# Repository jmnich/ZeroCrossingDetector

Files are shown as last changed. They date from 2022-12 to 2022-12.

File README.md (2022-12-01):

# Zero Crossing Detector (ZCD) 
*Designed for use with Fourier Transform Spectrometers.* 
This device converts symmetric sinusoidal signal from the reference beam detector into a TTL-compatible trigger for acquisition. 

Main features: 
- two TTL outputs 
- one intermediate monitor output
- one input 
- requires an external +-5 V symmetric supply
- accepts signals up to 20 V AC peak-peak +- 10 V DC
- input frequency up to 5 MHz
- hysteresis selectable with a rotary switch from about 20mV up to 2V 

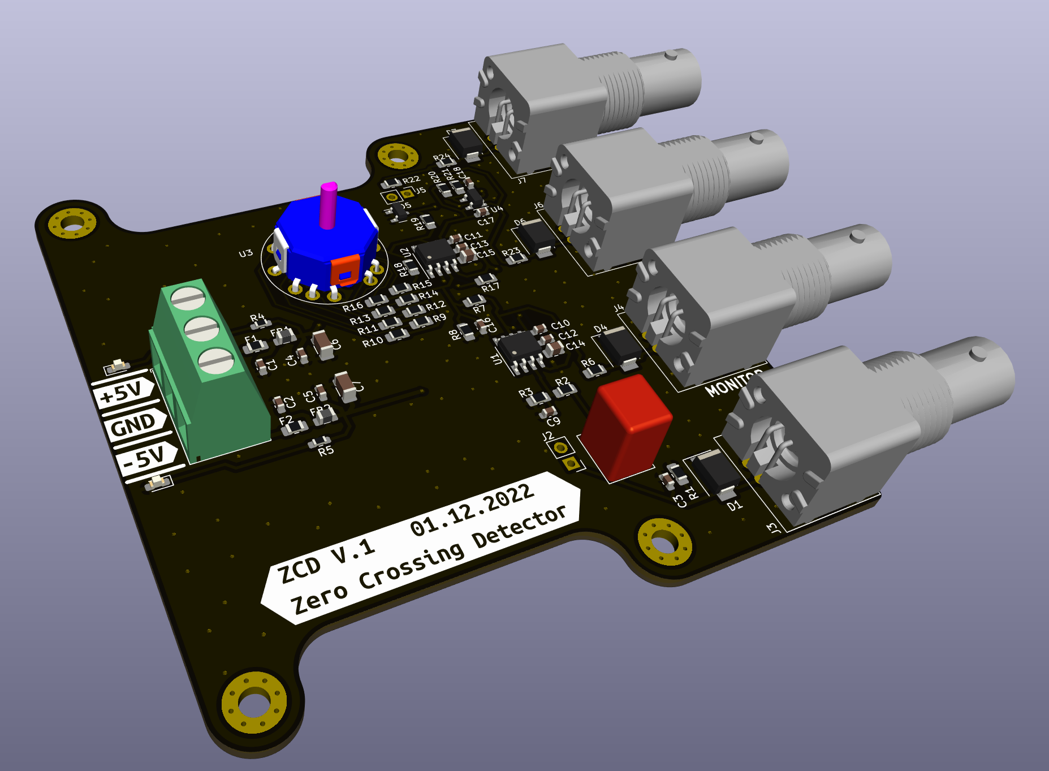
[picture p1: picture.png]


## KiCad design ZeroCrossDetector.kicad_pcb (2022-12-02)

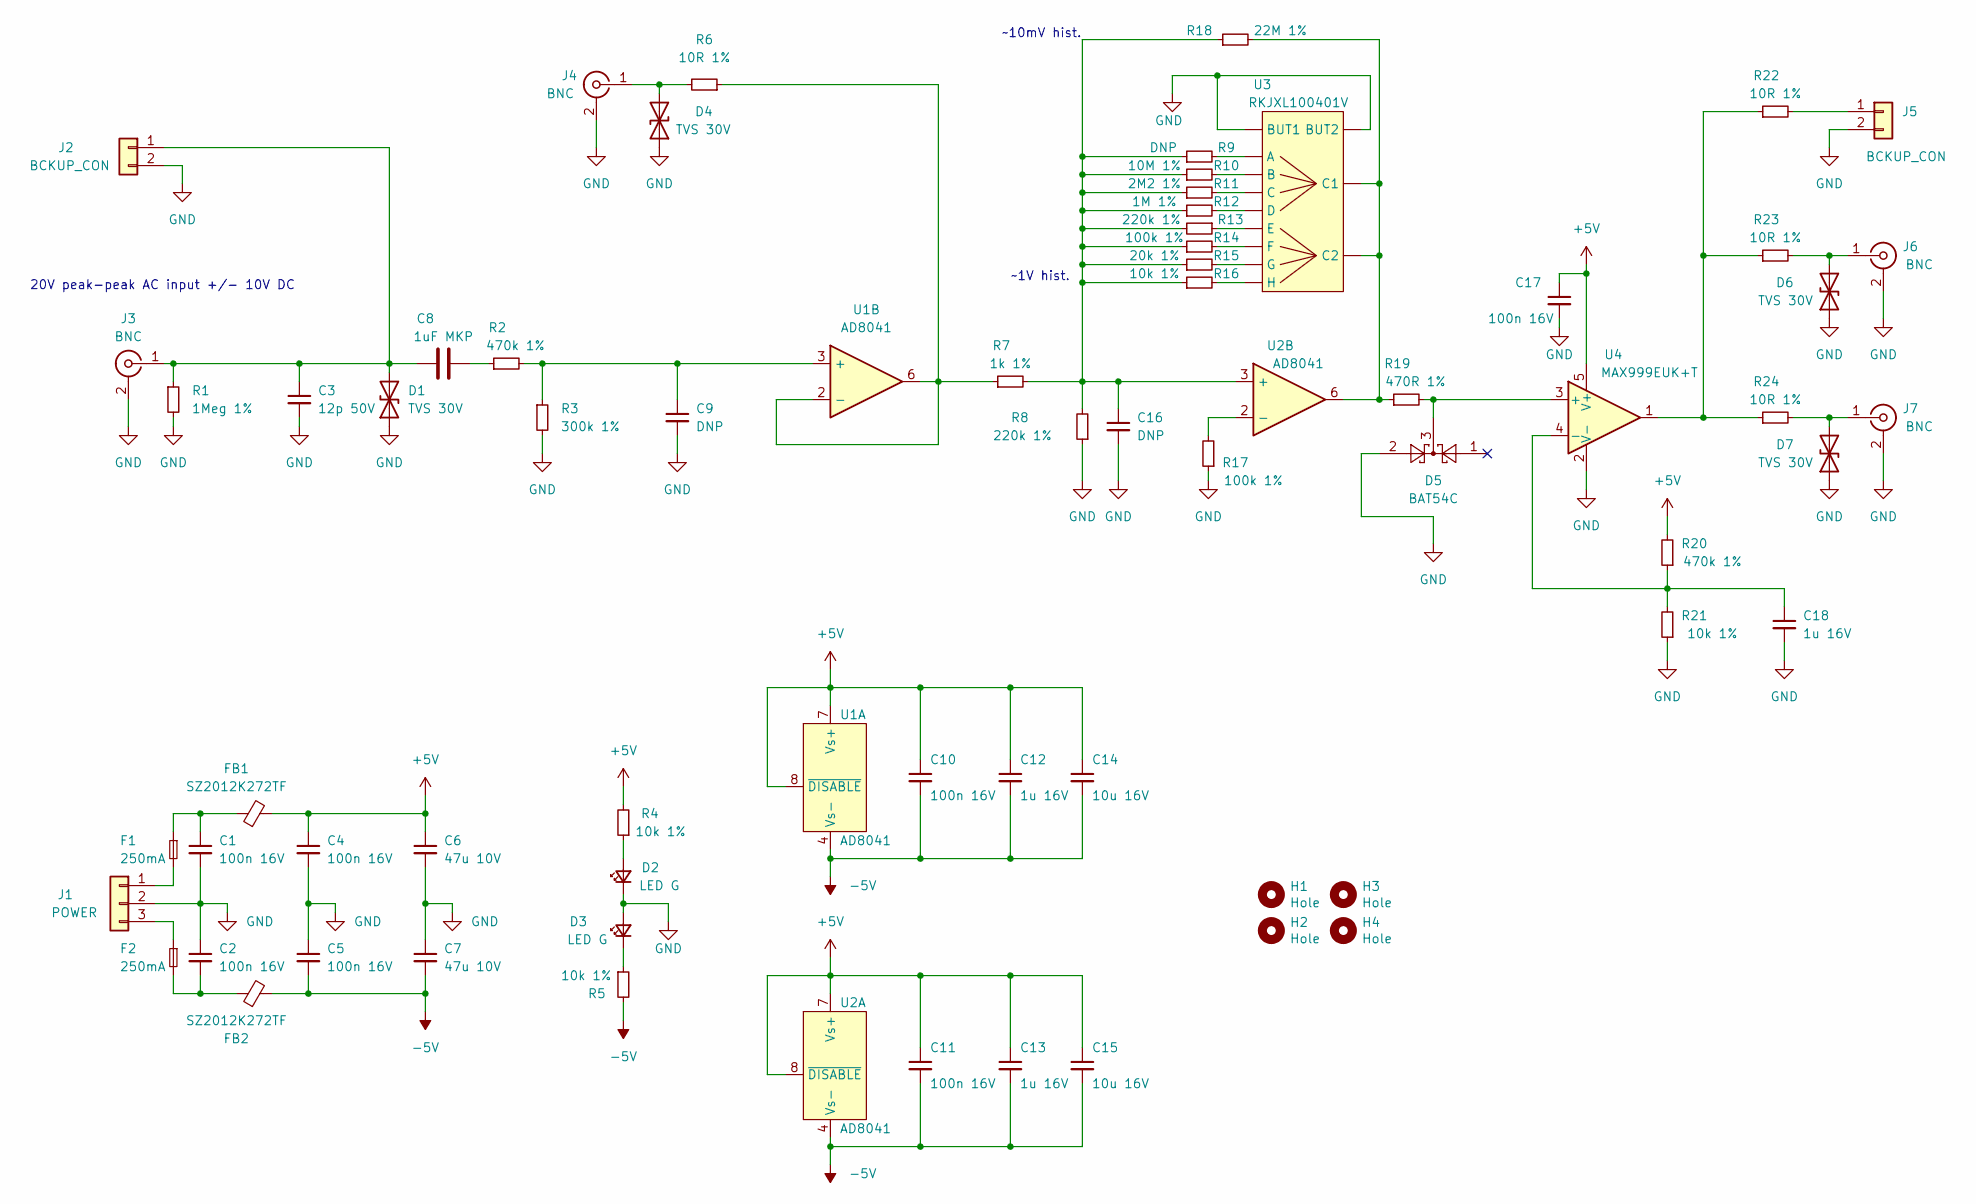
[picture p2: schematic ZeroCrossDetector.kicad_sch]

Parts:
C1, C2, C4, C5, C10, C11, C17: 100n 16V; C_0603_1608Metric; JLC C14663
C3: 12p 50V; C_0603_1608Metric; JLC C38523
C6, C7: 47u 10V; C_1206_3216Metric; JLC C96123
C8: 1uF MKP; C_Rect_L7.5mm_W6.5mm_P5.00mm; JLC C514201
C9, C16: DNP; C_0603_1608Metric
C12, C13, C18: 1u 16V; C_0603_1608Metric; JLC C15849
C14, C15: 10u 16V; C_0805_2012Metric; JLC C96446
D1, D4, D6, D7: TVS 30V; D_SMB; MPN SMBJ30CA/TR13; JLC C78418
D2, D3: LED G; LED_0603_1608Metric_Pad1.05x0.95mm_HandSolder; JLC C72043
D5: BAT54C; SOT-23; JLC C37704
F1, F2: 250mA; Fuse_0805_2012Metric_Pad1.15x1.40mm_HandSolder; JLC C269102
FB1, FB2: SZ2012K272TF; L_0805_2012Metric; MPN SZ2012K272TF; JLC C185876
H1, H2, H3, H4: Hole; MountingHole_3.2mm_M3_Pad_Via
J1: POWER; TerminalBlock_Phoenix_MKDS-1,5-3-5.08_1x03_P5.08mm_Horizont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; MPN DG500-5.08-03P-14-00A(H); JLC C581322
J2, J5: BCKUP_CON; PinHeader_1x02_P2.54mm_Vertical
J3, J4, J6, J7: BNC; BNC_Amphenol_B6252HB-NPP3G-50_Horizontal; JLC C2837587
R1: 1Meg 1%; R_0805_2012Metric_Pad1.20x1.40mm_HandSolder; JLC C17514
R2, R20: 470k 1%; R_0805_2012Metric_Pad1.20x1.40mm_HandSolder; JLC C17709
R3: 300k 1%; R_0805_2012Metric_Pad1.20x1.40mm_HandSolder; JLC C17616
R4, R5: 10k 1%; R_0603_1608Metric_Pad0.98x0.95mm_HandSolder; JLC C25804
R6, R22, R23, R24: 10R 1%; R_0805_2012Metric_Pad1.20x1.40mm_HandSolder; JLC C17415
R7: 1k 1%; R_0805_2012Metric_Pad1.20x1.40mm_HandSolder; JLC C17513
R8, R13: 220k 1%; R_0805_2012Metric_Pad1.20x1.40mm_HandSolder; JLC C17556
R9: DNP; R_0805_2012Metric_Pad1.20x1.40mm_HandSolder
R10: 10M 1%; R_0805_2012Metric_Pad1.20x1.40mm_HandSolder; JLC C26108
R11: 2M2 1%; R_0805_2012Metric_Pad1.20x1.40mm_HandSolder; JLC C26113
R12: 1M 1%; R_0805_2012Metric_Pad1.20x1.40mm_HandSolder; JLC C17514
R14, R17: 100k 1%; R_0805_2012Metric_Pad1.20x1.40mm_HandSolder; JLC C149504
R15: 20k 1%; R_0805_2012Metric_Pad1.20x1.40mm_HandSolder; JLC C4328
R16, R21: 10k 1%; R_0805_2012Metric_Pad1.20x1.40mm_HandSolder; JLC C17414
R18: 22M 1%; R_0805_2012Metric_Pad1.20x1.40mm_HandSolder; JLC C62398
R19: 470R 1%; R_0805_2012Metric_Pad1.20x1.40mm_HandSolder; JLC C17710
U1, U2: AD8041; SOIC-8_3.9x4.9mm_P1.27mm; MPN AD8041ARZ; JLC C90472
U3: RKJXL100401V; MPN RKJXL100401V; JLC C160838
U4: MAX999EUK+T; SOT-23-5; MPN MAX999EUK+T; JLC C124667

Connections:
+5V: C4.1, C6.1, C10.1, C11.1, C12.1, C13.1, C14.1, C15.1, C17.1, FB1.2, R4.2, R20.2, U1.7 (Vs+), U1.8 (~DISABLE), U2.7 (Vs+), U2.8 (~DISABLE), U4.5 (V+)
-5V: C5.2, C7.2, C10.2, C11.2, C12.2, C13.2, C14.2, C15.2, FB2.2, R5.2, U1.4 (Vs-), U2.4 (Vs-)
GND: C1.2, C2.1, C3.2, C4.2, C5.1, C6.2, C7.1, C9.2, C16.2, C17.2, C18.2, D1.1 (A1), D2.1 (K), D3.2 (A), D4.1 (A1), D5.2, D6.1 (A1), D7.1 (A1), J1.2, J2.2, J3.2 (Ext), J4.2 (Ext), J5.2, J6.2 (Ext), J7.2 (Ext), R1.2, R3.2, R8.1, R17.1, R21.1, U3.1 (BUT1), U3.2 (BUT2), U4.2 (V-)
unnamed: C1.1, F1.1, FB1.1
unnamed: C2.2, F2.2, FB2.1
unnamed: C3.1, C8.1, D1.2 (A2), J2.1, J3.1 (In), R1.1
unnamed: C8.2, R2.1
unnamed: C9.1, R2.2, R3.1, U1.3 (+)
unnamed: C16.1, R7.2, R8.2, R9.1, R10.1, R11.1, R12.1, R13.2, R14.1, R15.1, R16.1, R18.1, U2.3 (+)
unnamed: C18.1, R20.1, R21.2, U4.4 (-)
unnamed: D2.2 (A), R4.1
unnamed: D3.1 (K), R5.1
unnamed: D4.2 (A2), J4.1 (In), R6.2
unnamed: D5.3, R19.2, U4.3 (+)
unnamed: D6.2 (A2), J6.1 (In), R23.2
unnamed: D7.2 (A2), J7.1 (In), R24.2
unnamed: F1.2, J1.1
unnamed: F2.1, J1.3
unnamed: J5.1, R22.2
unnamed: R6.1, R7.1, U1.2 (-), U1.6
unnamed: R9.2, U3.A
unnamed: R17.2, U2.2 (-)
unnamed: R18.2, R19.1, U2.6, U3.C1, U3.C2
unnamed: R22.1, R23.1, R24.1, U4.1
unnamed: R10.2, U3.B
unnamed: R11.2, U3.C
unnamed: R12.2, U3.D
unnamed: R13.1, U3.E
unnamed: R14.2, U3.F
unnamed: R15.2, U3.G
unnamed: R16.2, U3.H

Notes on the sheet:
~1V hist.
20V peak-peak AC input +/- 10V DC
~10mV hist.

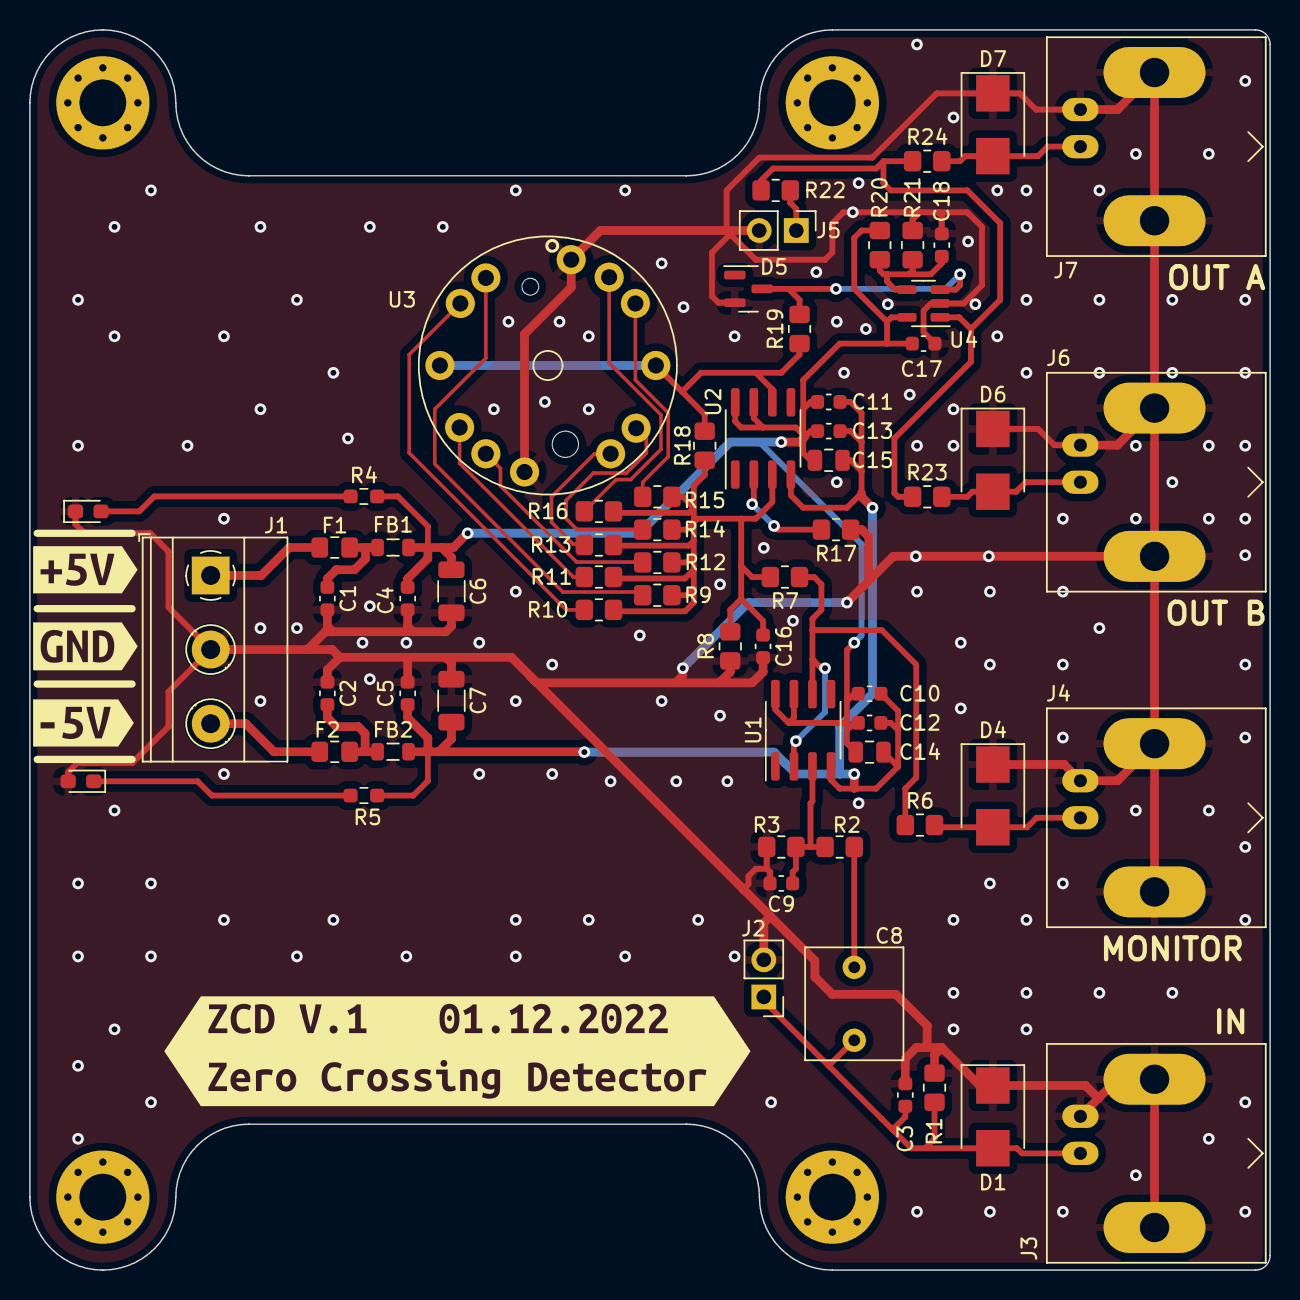
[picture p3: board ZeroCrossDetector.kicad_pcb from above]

Board: 2 copper layers, 85.0 x 85.0 mm, 72 parts (0 on the bottom side), 31 nets.

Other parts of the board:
kibuzzard-63889D11: G***; kibuzzard-63889D11
kibuzzard-63889DAC: G***; kibuzzard-63889DAC
kibuzzard-63889DB6: G***; kibuzzard-63889DB6
kibuzzard-63889DBE: G***; kibuzzard-63889DBE
